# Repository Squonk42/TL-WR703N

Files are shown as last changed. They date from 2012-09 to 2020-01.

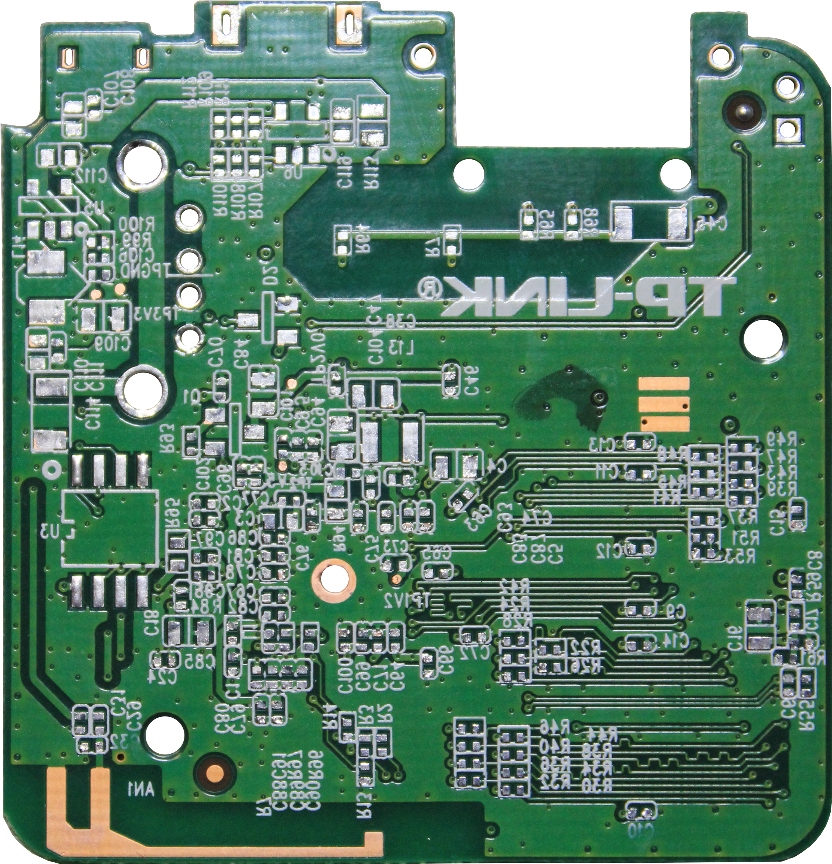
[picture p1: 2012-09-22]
Pictures/TL-WR703N Bare Board Bottom Mirrored.jpg

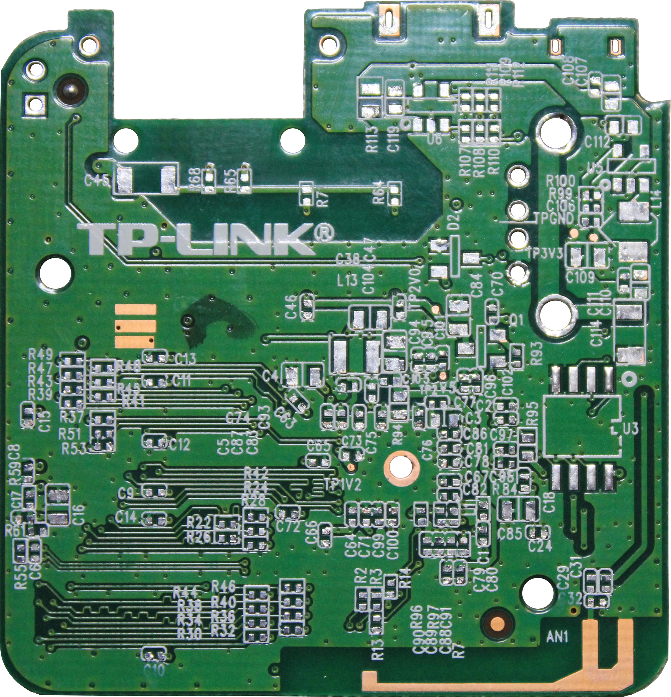
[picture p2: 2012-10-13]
Pictures/TL-WR703N Bare Board Bottom.jpg

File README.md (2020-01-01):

TL-WR703N
=========

Reverse Engineering work on the TP-LINK® TL-WR703N 150M 802.11n Wi-Fi Router

Check the http://squonk42.github.com/TL-WR703N/ web page for details.

### What?
Unlike what it is marketed for, the TP-LINK® TL-WR703N is not a “3G travel router”: it does not include a 3G modem at all, it simply means that the firmware support external USB 3G modems!

Despite this shortcoming, at less than $23, this device is the cheapest Wi-Fi router you can get west of the Pecos River! For this ridiculously low price, you get:

* A clean, small (57 mm x 57 mm x 18 mm) shiny white/light blue cover plastic case with rounded corners that is pretty easy to open with just a spudger or any other thin and resistant tool
* An Atheros AR9331 chipset with
 * An Atheros AR7040 400 MHz MISP24kc CPU
 * Integrated 802.11n 150 Mbps (130 Mbps real) Wi-Fi with 20 dBm (100 mW) output power
* 4 MB of serial (SPI) Flash memory
* 32 MB of DDR SDRAM
* An USB 2.0 host port
* A shielded Ethernet 10/100 Mbps RJ45 jack
* An external power supply using a provided wall plug via a micro-USB socket
* A software-controlled reset pinhole switch
* A blue surface-mounted LED (that can be replaced by a 3 mm through-hole LED)
* A built-in Wi-Fi printed antenna (that can be replaced by an external one)
* An UART accessible via 2 tiny pads that provides access to the uBoot bootloader and the Linux 2.6 console

This device was released in August 2011 in China, and is not exported, though it is easy to get one on eBay.

There is also a closely related sister device as the TP-LINK® TL-MR3020 for the export market, with the following differences:

* It is CE/FCC certified
* It has 4 additional surface-mounted LEDs
* It has an additional sliding switch with 3 positions
* The reset button is combined with the WPS LED
* It has 2 Wi-Fi printed antennas, but only one is actually used
* The RJ45 Ethernet jack is not shielded
* The UART is available on a nice 0.1” pitch through-hole connector (not mounted)
* It is larger: 67 mm x 74 mm x 22 mm)
* It is more expensive: $39 on eBay

### Why?
Because of these interesting characteristics, people started to imagine unforeseen applications for the cheapest available embedded Linux platform on the market, ranging from software-only firmware customization, to hardware hacks involving fine pitch soldering in order to control various physical devices.

The manufacturer (TP-LINK) is making its best efforts to comply with the requirements of the GPL license by providing access to [sources releases of the modified GPL software used in the original firmware](http://www.tp-link.com/en/support/gpl/) (actually, those of the related [TL-MR3020 device](http://www.tp-link.com/en/support/gpl/?categoryid=547), but they are close enough). Although not useable as is, all these modifications has been ported to several existing embedded Linux distributions, and the dedicated embedded [OpenWRT distribution](https://openwrt.org/) is an excellent choice for its easy build system and support for bleeding-edge packages.

Naturally, the hardware-focused projects using the TL-WR703N tend to be centralized in a few OpenWRT forum threads ([[1]](https://forum.openwrt.org/viewtopic.php?id=36471), [[2]](https://forum.openwrt.org/viewtopic.php?id=38994), [[3]](https://forum.openwrt.org/viewtopic.php?id=39567), [[4]](https://forum.openwrt.org/viewtopic.php?id=34437), and [[5]](https://forum.openwrt.org/viewtopic.php?id=31729)), and rapidly focused on the research of available I/O resources and low-level electronic understanding. In this regard, the TL-WR703N router suffers from a complete lack of information reagarding its hardware implementation:

* The datasheet for the main chip (Atheros AR9331) is only available under NDA (Non-Disclosure Agreement)
* No available schematic, layout or BOM (Bill Of Materials) files

Although some progress has been made, like an almost exhaustive main AR9331 chip pinout and a component-by-component description, only a full reverse-engineering work can provide the answers to all the questions people will have on the TL-WR703N hardware.

So the goal of this reverse-engineering of the TP-LINK® TL-WR703N router hardware is not to reproduce the device as is, as both the main chip is not available for retail, and because it would be difficult to beat the already low prices achieved by the Chinese manufacturer anyway. But the main purpose of this work is to provide the knowledge required to fully understand the hardware of this amazing little device.

### Who?
This is the work of a single person (Michel Stempin), based on the [TP-LINK® TL-WR703N teardown](http://www.kean.com.au/oshw/WR703N/teardown/) performed by Kean from the OpenWRT forum.

### Where?
All the resulting files are available in the [corresponding GitHub repository](https://github.com/Squonk42/TL-WR703N), and discussions are taking place into the corresponding threads from the [OpenWRT forum](https://forum.openwrt.org/).

The CAD files are designed using [EagleCAD v6.10](http://www.cadsoftusa.com/eagle-pcb-design-software/?language=en). Despite the fact that the free version is limited to 2 layers only and that the boards has more layers than that, this should not be too much of a problem, as there are only a few signals located into the internal layers.

So any question, idea, remark can be posted there!

### When?
This work took around 150 hours (2 week-ends and all the evenings in-between on my spare time) to produce a first PCB layout from the raw PCB top and bottom pictures.

But spare time costs nothing, and hobbyist motivation is higher than normal paid work!

### How?
If I remember correctly, Kean took the PCB pictures using an 18 Mpx camera. Removing all borders and cleaning up the original pictures, this resulted into images of 3090 x 3210 pixels. As the PCB is approximately 1.9" x 1.9", the achieved resolution is something close to 1600 dpi, or a little bit better than a common 1200/2400 dpi flat bed scanner in one direction, worse in the other.

The drawback is that using a camera with a large depth of field, the image is not perfect. It contains:
* perspective (i.e. board edges are not parallel, and are not parallel either to the picture edges)
* a "barrel" effect due to the lens in macro mode
* pixels are not necessarily "square" in X and Y
* the actual scale is unknown

The first step was thus to clean up the picture using the perspective correction function of PS as a picture editing tool to straighten borders.

As for the other 2 next problems, the trick was to find something into these pictures that can be taken as a reference with known dimensions: the best guess was to take a large chip with numerous evenly-spaced pads, like the main AR9331 SoC U1 or the SDRAM chip U2. Using the same graphical editing program as used above, tools for correcting the lens "barrel" effect and scale differently in X and Y were used to get perfectly square pixels.

Now, both sides couldn't be directly superimposed: holes, vias and the PCB contour itself did not match correctly. A good way to fix this problem was to use PS's "puppet warp transform" tool with the 2 PCB sides on separate layers with transparency. This tool allowed to place and drag pins over the picture, so it could be stretched locally. Using this technique, it was possible to make both sides match perfectly by first placing pins at the 4 corners, then adding more pins as required until a perfect match was obtained.

At this point, 2 perfectly matched/square pictures with a resolution close to the original snapshots were available.

The last problem related to unknown scale required to perform a resize operation on these pictures, so they can be superimposed with the PCB in the ECAD software used ([EagleCAD](http://www.cadsoftusa.com/eagle-pcb-design-software/?language=en)). Again, the same chips as above were taken as references with known dimensions. Based on the datasheets, their footprint was first created into EagleCAD with exact "real" dimensions, then placed into an empty PCB file.

As I still use Windows XP, I had to use the [Glass2K](http://chime.tv/products/glass2k.shtml) utility to get either a transparent EagleCAD or picture window. Putting the EagleCAD window as large as possible on my screen, I aligned the footprint with the picture, by scaling the picture so that the round 25% picture scale was matching the EagleCAD full screen display.

By adjusting EagleCAD zoom factor from the default 1.2 to 2, it is now possible on my screen to scale the picture to 50/100/200% while zooming along with EagleCAD, and thus zoom into details "almost" easily.

That was all for the pictures, no editing any more! The drawback is that because of this last step, they are adjusted to my screen setup and cannot be shared with others easily.

The next big job was then to create all the component footprints as an EagleCAD part library. Having 2 screens helped a lot in this case, and using transparency as above, it was possible to check that the footprint was correct directly into the picture. Still, this was a tedious job. As I was doing that, I took this opportunity to also create the corresponding schematic symbols and the parts for tying the symbols and the footprints together.

Once all the parts were created, I placed them onto the PCB/picture as accurately as possible, then started to route all traces in between. There was a trick to integrate existing vias into a trace: I had to get info on the via to find its signal name, then name the trace using the same name, so they both belong to the same signal. Also, when there was only a single signal pad to connect to a via, I had to artificially add a dummy part to first create a ratsnet between 2 pads, get via info/name the ratsnest as explained, then destroy the dummy part...

I used a 1 mm/0.05 mm grid, and only a few different trace widths. However, I had to create 2 signal "classes" with different clearance values to create the correct ground/power planes.

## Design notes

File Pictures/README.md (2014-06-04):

**Note:** The "TL-WR703N Schematic EagleCAD.png" file is huge (26731x18331), so opening it directly within your browser may cause it to crash!

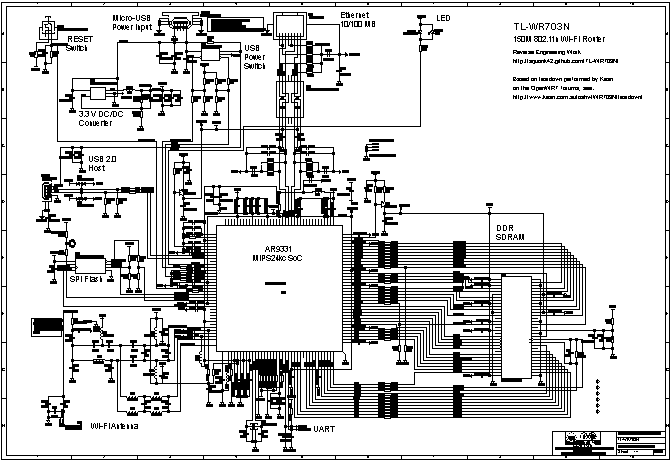
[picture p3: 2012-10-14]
Pictures/TL-WR703N Schematic LoRes.png

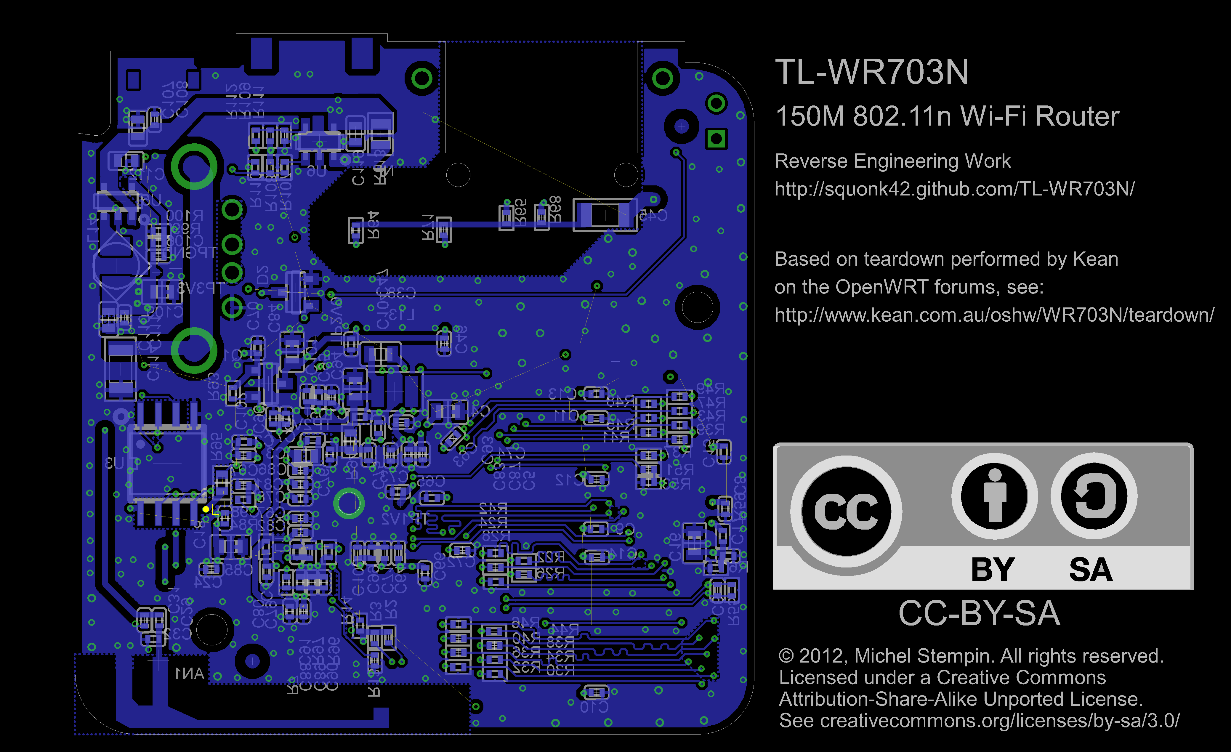
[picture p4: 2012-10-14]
Pictures/TL-WR703N Bottom EagleCAD.png

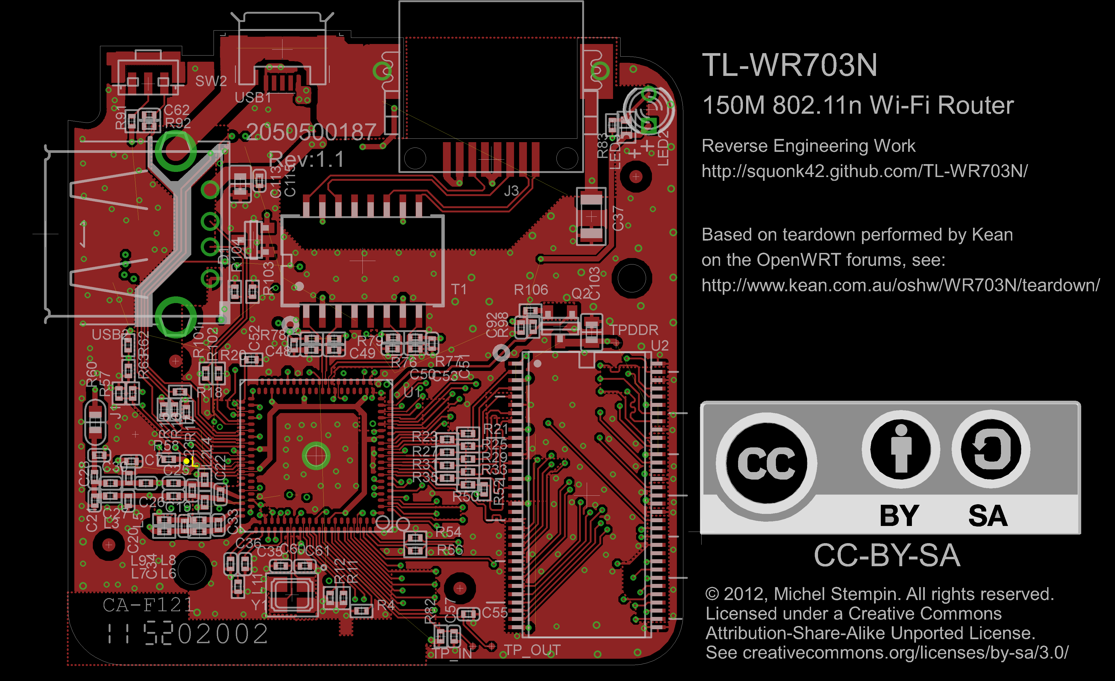
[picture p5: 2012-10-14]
Pictures/TL-WR703N Top EagleCAD.png

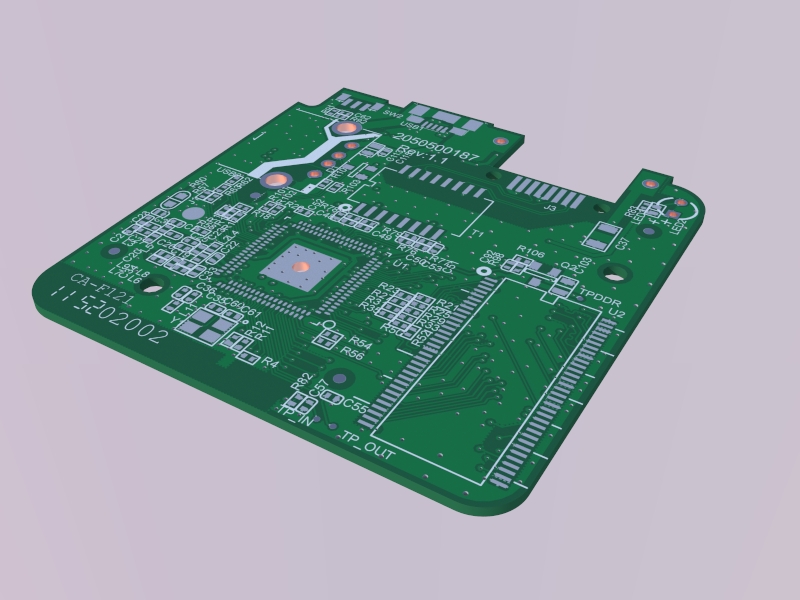
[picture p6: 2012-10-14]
Pictures/TL-WR703N 3D.jpg

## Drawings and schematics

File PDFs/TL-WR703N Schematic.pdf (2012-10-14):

# TL-WR703N

# 150M 802.11n Wi-Fi Router

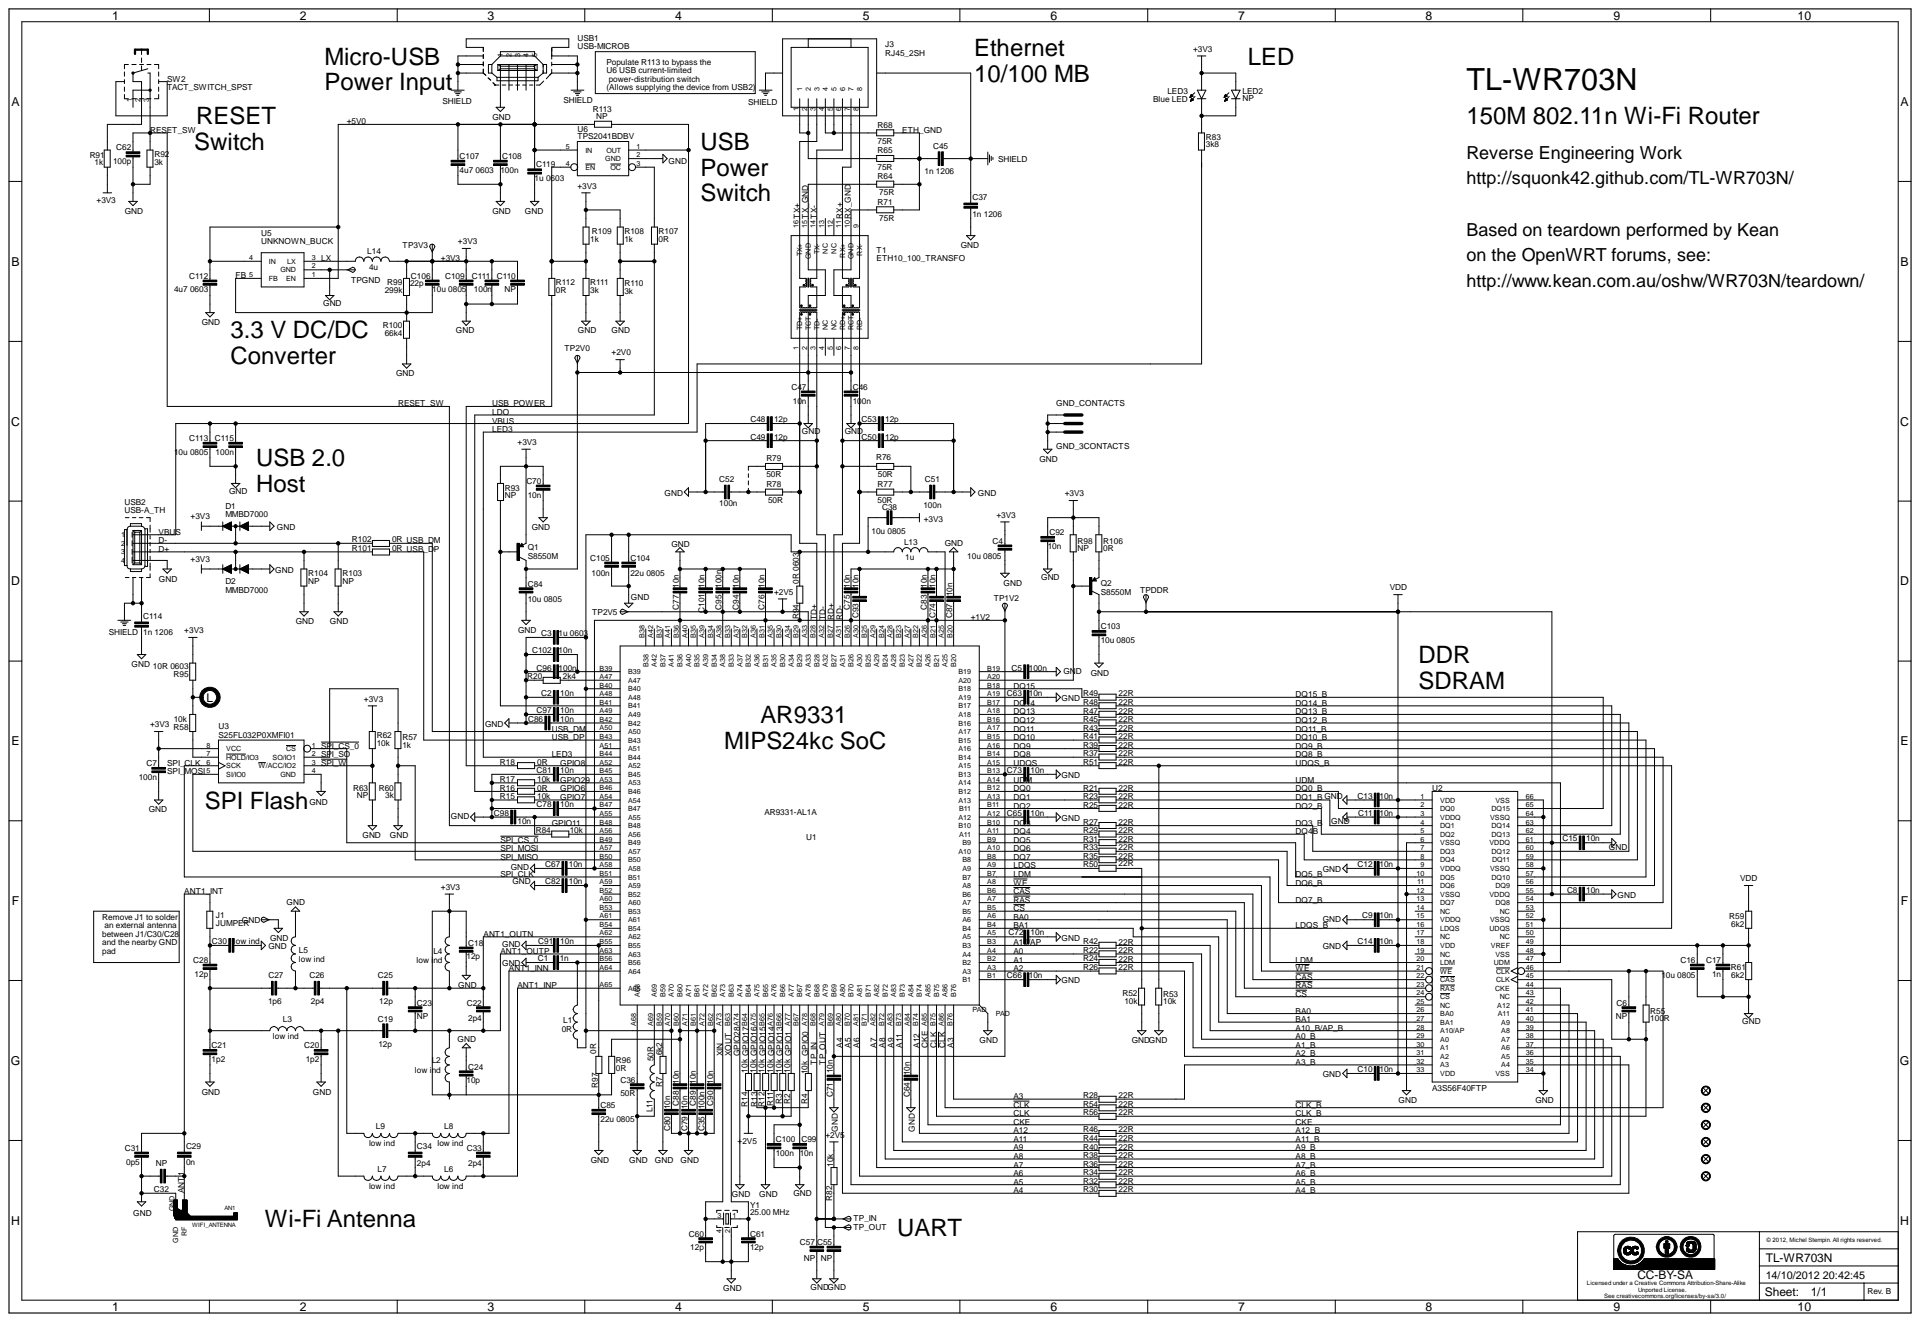
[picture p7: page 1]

Populate R113 to bypass the
U6 USB current-limited
power-distribution switch
(Allows supplying the device from USB2)

Reverse Engineering Work
http://squonk42.github.com/TL-WR703N/

Based on teardown performed by Kean
on the OpenWRT forums, see:
http://www.kean.com.au/oshw/WR703N/teardown/

D+ | R101 0R USB_DP

Remove J1 to solder
an external antenna
between J1/C30/C28
and the nearby GND
pad

Licensed under a Creative Commons Attribution-Share-Alike
See creativecommons.org/licenses/by-sa/3.0/

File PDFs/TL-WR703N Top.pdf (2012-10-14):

2050500187

# TL-WR703N

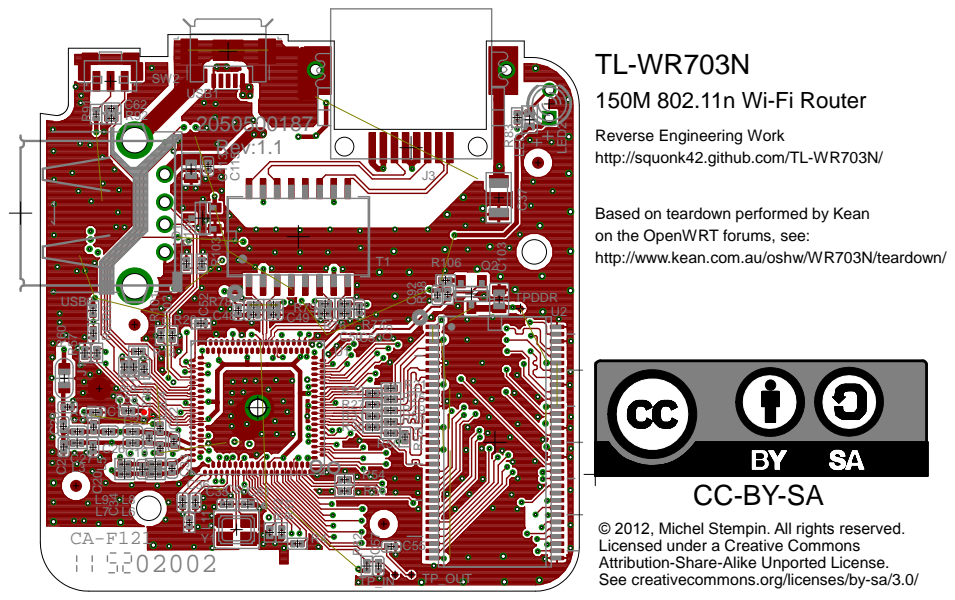
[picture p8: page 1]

LED2
Reverse Engineering Work
http://squonk42.github.com/TL-WR703N/

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

© 2012, Michel Stempin. All rights reserved.
Licensed under a Creative Commons
Attribution-Share-Alike Unported License.
See creativecommons.org/licenses/by-sa/3.0/

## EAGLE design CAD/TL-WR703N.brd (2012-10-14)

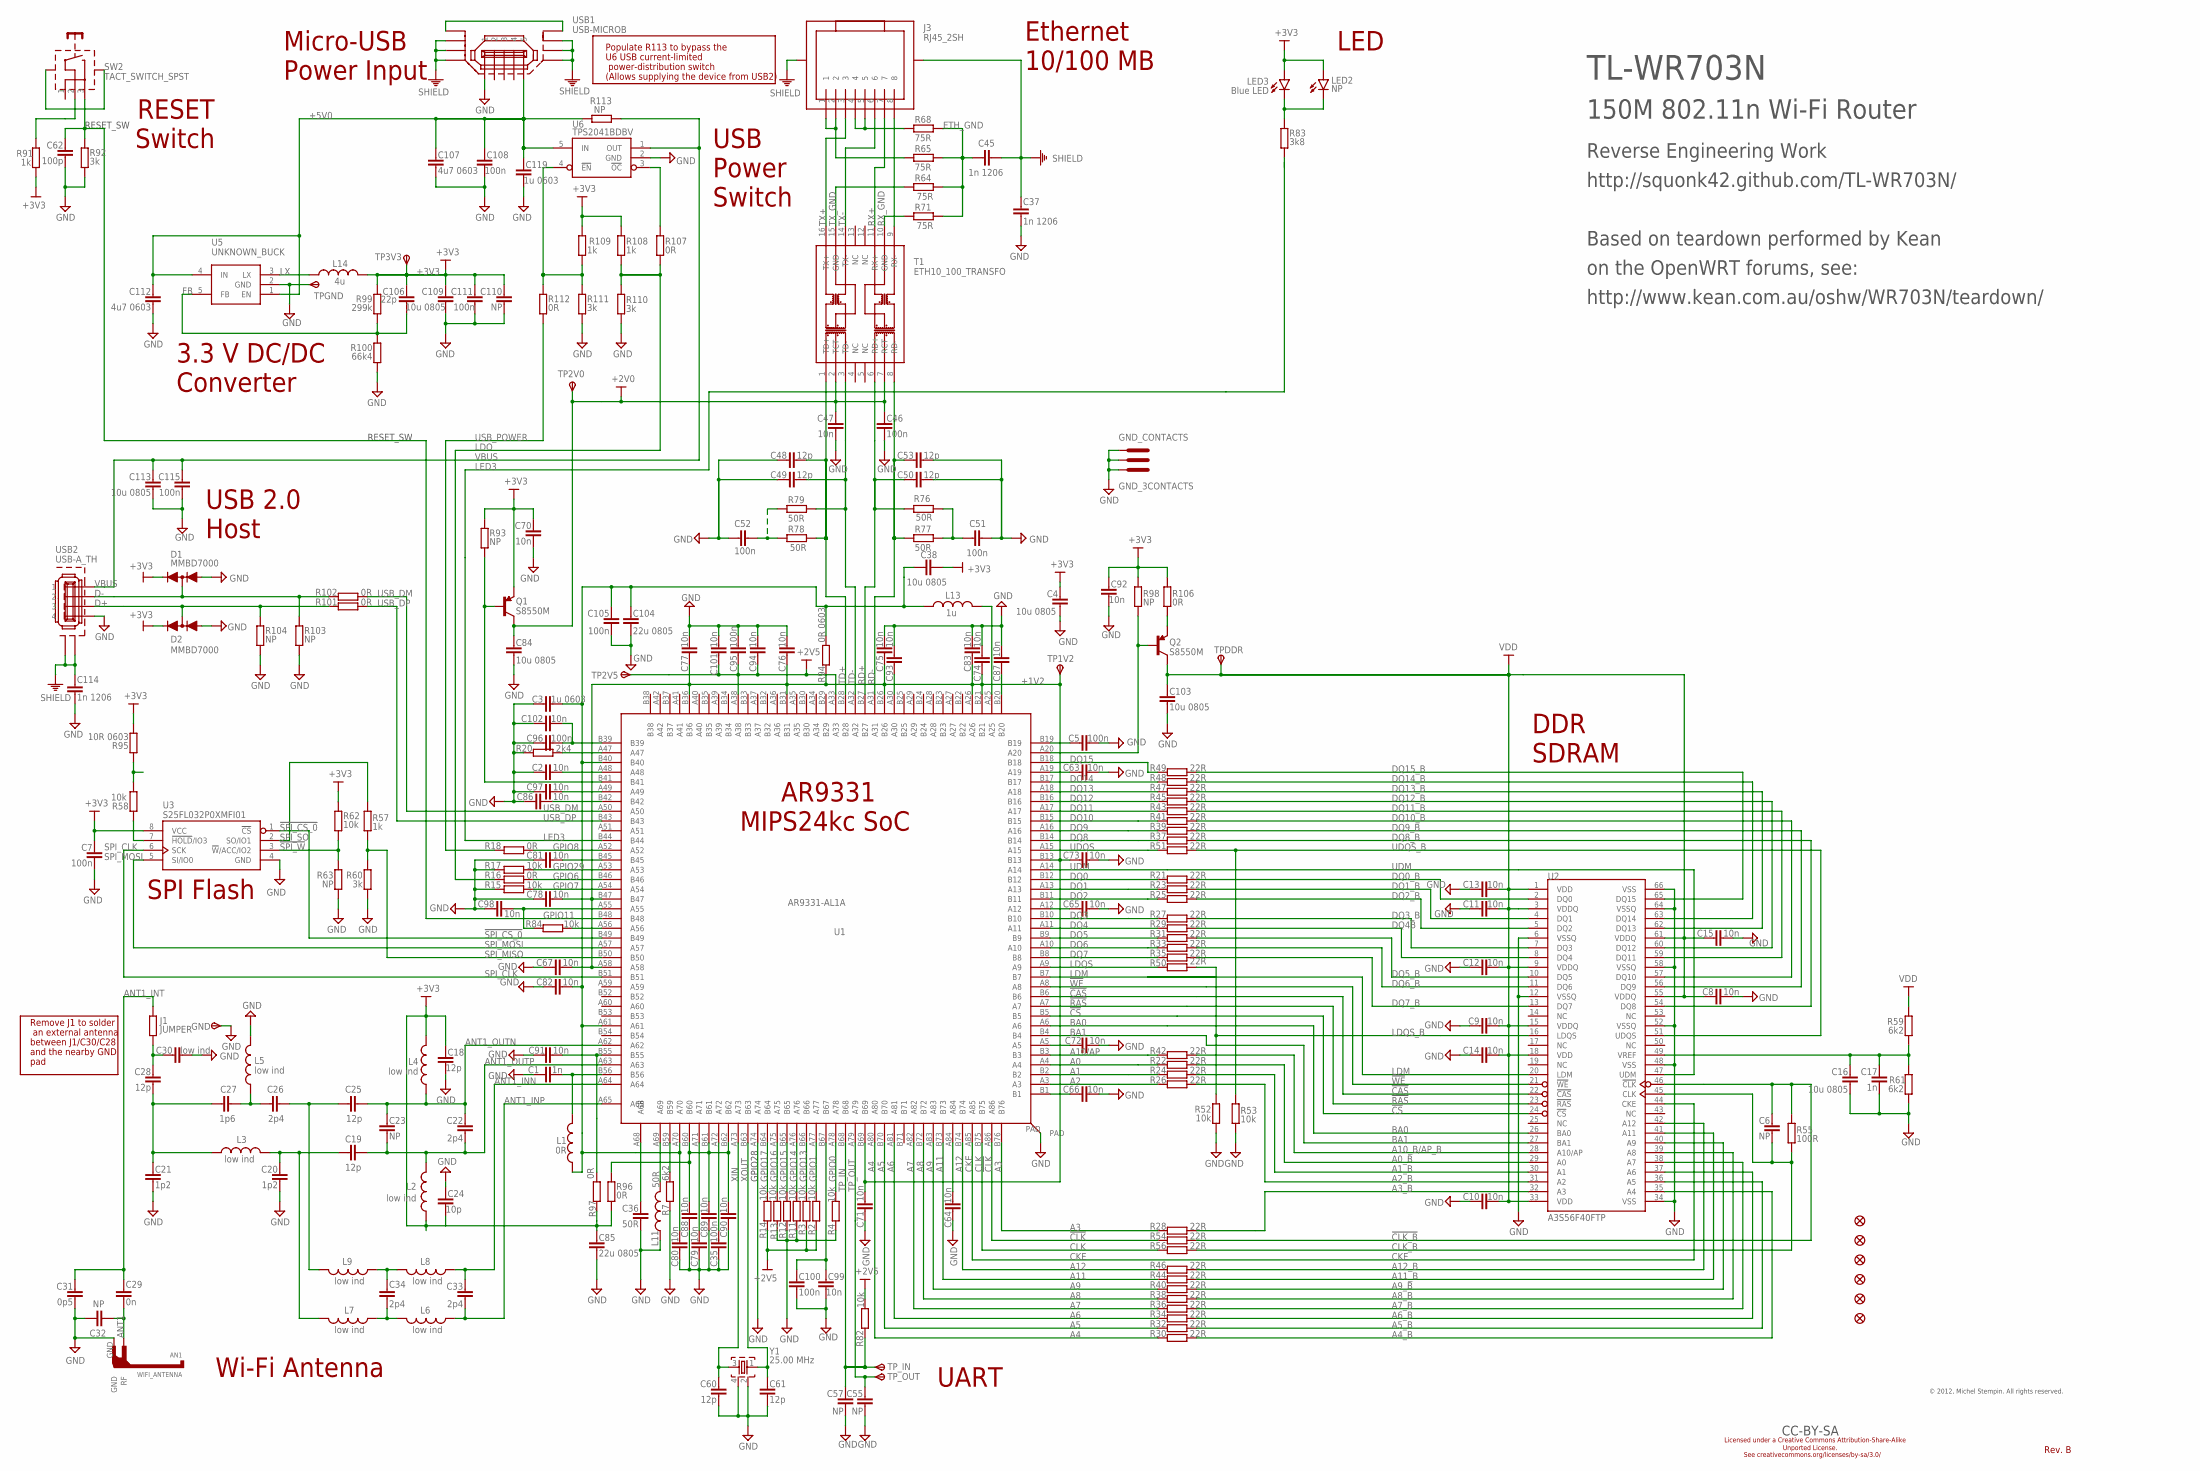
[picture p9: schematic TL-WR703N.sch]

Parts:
AN1: WIFI_ANTENNA
C1, C17: 1n; C0402
C2, C8, C9, C10, C11, C12, C13, C14, C15, C47, C63, C64, C65, C66, C67, C70, C71, C72, C73, C74, C75, C76, C77, C78, C79, C80, C81, C82, C83, C86, C87, C88, C89, C90, C91, C92, C93, C94, C97, C98, C99, C101, C102: 10n; C0402
C3, C119: 1u 0603; C0603
C4, C16, C38, C84, C103, C109, C113: 10u 0805; C0805
C5, C7, C35, C46, C51, C52, C95, C96, C100, C105, C108, C111, C115: 100n; C0402
C6, C23, C32, C55, C57: NP; C0402
C18, C19, C25, C28, C48, C49, C50, C53, C60, C61: 12p; C0402
C20, C21: 1p2; C0402
C22, C26, C33, C34: 2p4; C0402
C24: 10p; C0402
C27: 1p6; C0402
C29: 0n; C0402
C30: low ind; C0402
C31: 0p5; C0402
C36: 50R; C0402
C37, C45, C114: 1n 1206; C1206
C62: 100p; C0402
C85, C104: 22u 0805; C0805
C106: 22p; C0402
C107, C112: 4u7 0603; C0603
C110: NP; C0603
D1, D2: MMBD7000; SOT23-3
E$1, E$2, E$3, E$4, E$5, E$6: FIDUCIAL
E$7: CC-BY-SA
GND: TEST_PAD_SHIELD; SHIELD_PAD
GND_CONTACTS: GND_3CONTACTS; GND_3CONTACT
J1: JUMPER; J0603
J3: RJ45_2SH; RJ45_LP_RA_SMT
L1: 0R; L0402
L2, L3, L4, L5, L6, L7, L8, L9: low ind; L0402
L11: 50R; L0402
L13: 1u; L1008
L14: 4u; FERRITE_SELF
LED2: NP; LED3MM
LED3: Blue LED; LED0603
Q1, Q2: S8550M; SOT23-3
R2, R3, R4, R11, R12, R13, R14, R15, R17, R52, R53, R58, R62, R82, R84: 10k; R0402
R7, R59, R61: 6k2; R0402
R16, R18, R96, R97, R101, R102, R106, R107, R112: 0R; R0402
R20: 2k4; R0402
R21, R22, R23, R24, R25, R26, R27, R28, R29, R30, R31, R32, R33, R34, R35, R36, R37, R38, R39, R40, R41, R42, R43, R44, R45, R46, R47, R48, R49, R50, R51, R54, R56: 22R; R0402
R55: 100R; R0402
R57, R91, R108, R109: 1k; R0402
R60, R92, R110, R111: 3k; R0402
R63, R93, R98, R103, R104: NP; R0402
R64, R65, R68, R71: 75R; R0402
R76, R77, R78, R79: 50R; R0402
R83: 3k8; R0402
R94: 0R 0603; R0603
R95: 10R 0603; R0603
R99: 299k; R0402
R100: 66k4; R0402
R113: NP; R0805
SW2: TACT_SWITCH_SPST; TACT_SWITCH_SPST_RA_SMT
T1: ETH10_100_TRANSFO; H1601CG
TP1V2, TP2V0, TP2V5, TP3V3: TEST_PAD
TPDDR: TEST_PAD
TPGND: TEST_PAD
TP_IN: TEST_PAD
TP_OUT: TEST_PAD
U1: AR9331-AL1A; DRMLF164
U2: A3S56F40FTP; TSOP66
U3: S25FL032P0XMFI01; SOP8
U5: UNKNOWN_BUCK; SOT23-5
U6: TPS2041BDBV; SOT23-5
USB1: USB-MICROB
USB2: USB-A_TH
Y1: 25.00 MHz; CRYSTAL_32_25

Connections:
!CAS: U1.B6, U2.22 (!CAS)
!CLK: R54.1, U1.A86
!CLK_B: C6.2, R54.2, R55.2, U2.46 (!CLK)
!CS: U1.B5, U2.24 (!CS)
!RAS: U1.A7, U2.23 (!RAS)
!SPI_CS_0: U1.B49, U3.1 (!CS)
!SPI_W: R62.2, R63.1, U3.3 (!W!/ACC/IO2)
!WE: U1.A8, U2.21 (!WE)
$28: C52.2, R78.1, R79.2
+1V2: C67.2, C71.2, C73.1, C74.2, C75.1, C76.1, C77.2, C78.2, C83.1, R94.2, TP1V2.1, U1.A26, U1.A58, U1.B13, U1.B21, U1.B26, U1.B31, U1.B36, U1.B47, U1.B69
+2V0: C46.1, C47.1, C84.2, Q1.3 (C), T1.2 (TCT), T1.7 (RCT), TP2V0.1
+2V5: C94.2, C95.2, C101.2, R2.1, R3.1, R14.2, R82.1, TP2V5.1, U1.A33, U1.A38
+3V3: C4.2, C7.1, C18.1, C24.1, C38.2, C70.2, C85.2, C92.2, C106.2, C109.2, C110.1, C111.1, D1.2 (C), D2.2 (C), L2.1, L4.2, L14.1, LED2.A, LED3.A, Q1.2 (E), R62.1, R91.1, R93.2, R95.1, R96.2, R97.2, R98.2, R99.2, R106.2, R108.2, R109.1, TP3V3.1, U3.8 (VCC)
+5V0: C107.2, C108.2, C112.1, C119.1, R113.1, U5.1 (EN), U5.4 (IN), U6.5 (IN), USB1.VBUS (5)
A0: R22.1, U1.A4
A0_B: R22.2, U2.29 (A0)
A1: R24.1, U1.B2
A1_B: R24.2, U2.30 (A1)
A2: R26.1, U1.A3
A2_B: R26.2, U2.31 (A2)
A3: R28.1, U1.B76
A3_B: R28.2, U2.32 (A3)
A4: R30.1, U1.A80
A4_B: R30.2, U2.35 (A4)
A5: R32.1, U1.B70
A5_B: R32.2, U2.36 (A5)
A6: R34.1, U1.A81
A6_B: R34.2, U2.37 (A6)
A7: R36.1, U1.A82
A7_B: R36.2, U2.38 (A7)
A8: R38.1, U1.B72
A8_B: R38.2, U2.39 (A8)
A9: R40.1, U1.A83
A9_B: R40.2, U2.40 (A9)
A10/AP: R42.1, U1.B3
A10_B/AP_B: R42.2, U2.28 (A10/AP)
A11: R44.1, U1.B73
A11_B: R44.2, U2.41 (A11)
A12: R46.1, U1.B74
A12_B: R46.2, U2.42 (A12)
ANT1: AN1.RF, C29.2, C32.2
ANT1_INN: C33.2, L8.1, U1.A64
ANT1_INP: C33.1, L6.1, U1.A65
ANT1_INT: C29.1, C31.1, J1.2
ANT1_OUTN: C22.2, C23.2, C25.2, L4.1, U1.A62
ANT1_OUTP: C19.2, C22.1, C23.1, L2.2, U1.A63
BA0: U1.A6, U2.26 (BA0)
BA1: U1.B4, U2.27 (BA1)
CKE: U1.A85, U2.44 (CKE)
CLK: R56.1, U1.B75
CLK_B: C6.1, R55.1, R56.2, U2.45 (CLK)
D+: D2.3 (M), R101.1, R104.1, USB2.3
D-: D1.3 (M), R102.1, R103.1, USB2.2
DQ0: R21.2, U1.B12
DQ0_B: R21.1, U2.2 (DQ0)
DQ1: R23.2, U1.A13
DQ1_B: R23.1, U2.4 (DQ1)
DQ2: R25.2, U1.B11
DQ2_B: R25.1, U2.5 (DQ2)
DQ3: R27.2, U1.B10
DQ3_B: R27.1, U2.7 (DQ3)
DQ4: R29.2, U1.A11
DQ4B: R29.1, U2.8 (DQ4)
DQ5: R31.2, U1.B9
DQ5_B: R31.1, U2.10 (DQ5)
DQ6: R33.2, U1.A10
DQ6_B: R33.1, U2.11 (DQ6)
DQ7: R35.2, U1.B8
DQ7_B: R35.1, U2.13 (DQ7)
DQ8: R37.1, U1.B14
DQ8_B: R37.2, U2.54 (DQ8)
DQ9: R39.1, U1.A16
DQ9_B: R39.2, U2.56 (DQ9)
DQ10: R41.1, U1.B15
DQ10_B: R41.2, U2.57 (DQ10)
DQ11: R43.1, U1.A17
DQ11_B: R43.2, U2.59 (DQ11)
DQ12: R45.1, U1.B16
DQ12_B: R45.2, U2.60 (DQ12)
DQ13: R47.1, U1.A18
DQ13_B: R47.2, U2.62 (DQ13)
DQ14: R48.1, U1.B17
DQ14_B: R48.2, U2.63 (DQ14)
DQ15: R49.1, U1.B18
DQ15_B: R49.2, U2.65 (DQ15)
ETH_GND: C45.2, R64.1, R65.2, R68.2, R71.1
FB: C106.1, R99.1, R100.2, U5.5 (FB)
GND: AN1.GND, C1.2, C2.2, C3.2, C4.1, C5.2, C7.2, C8.2, C9.1, C10.1, C11.1, C12.1, C13.1, C14.1, C15.2, C16.1, C17.1, C18.2, C20.1, C21.1, C24.2, C30.2, C31.2, C32.1, C35.1, C36.1, C37.1, C46.2, C47.2, C48.1, C49.2, C50.1, C51.1, C52.1, C53.2, C55.2, C57.1, C60.1, C61.2, C62.1, C63.1, C64.1, C65.2, C66.1, C67.1, C70.1, C71.1, C72.1, C73.2, C74.1, C75.2, C76.2, C77.1, C78.1, C79.2, C80.2, C81.1, C82.1, C83.2, C84.1, C85.1, C86.1, C87.2, C88.2, C89.2, C90.2, C91.1, C92.1, C93.1, C94.1, C95.1, C96.1, C97.2, C98.2, C99.1, C100.1, C101.1, C102.1, C103.2, C104.2, C105.2, C107.1, C108.1, C109.1, C110.2, C111.2, C112.2, C113.1, C114.2, C115.1, C119.2, D1.1 (A), D2.1 (A), GND.1, GND_CONTACTS.GND$1, GND_CONTACTS.GND$2, GND_CONTACTS.GND$3, L5.2, L11.1, R4.2, R7.2, R11.1, R12.1, R13.2, R15.1, R17.1, R20.2, R52.2, R53.1, R60.1, R61.2, R63.2, R92.1, R100.1, R103.2, R104.2, R110.2, R111.1, TPGND.1, U1.A74, U1.PAD, U2.6 (VSSQ), U2.12 (VSSQ), U2.34 (VSS), U2.48 (VSS), U2.52 (VSSQ), U2.58 (VSSQ), U2.64 (VSSQ), U2.66 (VSS), U3.4 (GND), U5.2 (GND), U6.2 (GND), USB1.GND (1), USB2.4, Y1.2, Y1.4
GPIO0: R4.1, U1.A78
GPIO1: R2.2, U1.A77
GPIO6: R16.2, U1.B46
GPIO7: R15.2, U1.A54
GPIO8: R18.2, U1.A52
GPIO11: C62.2, R92.2, SW2.3, U1.B48
GPIO13: R3.2, U1.B66
GPIO14: R11.2, U1.A76
GPIO15: R12.2, U1.B65
GPIO16: R13.1, U1.A75
GPIO17: R14.1, U1.B64
GPIO29: R17.2, U1.A53
LDM: U1.B7, U2.20 (LDM)
LDO: R16.1, R107.1, R108.1, R110.1
LDQS: R50.2, U1.A9
LDQS_B: R50.1, R52.1, U2.16 (LDQS)
LED3: R83.1, U1.B44
LX: L14.2, U5.3 (LX)
unnamed: C79.1, U1.A71
RD+: C50.2, R76.2, T1.6 (RD+), U1.B27
RD-: C53.1, R77.1, T1.8 (RD-), U1.A31
RX+: J3.7, T1.11 (RX+)
RX-: J3.8, T1.9 (RX-)
RX_GND: R71.2, T1.10 (GND)
S$15: C99.2, C100.2, U1.B67
S$17: C19.1, C20.2, L3.2, L7.2
S$18: C3.1, C38.1, C80.1, C82.2, C104.1, C105.1, L1.2, L13.1, R94.1, U1.A61, U1.A70, U1.B40
S$36: C65.1, U1.A12
S$44: C16.2, C17.2, R59.2, R61.1, U2.49 (VREF)
S$54: C51.2, R76.1, R77.2
S$55: LED2.K (C), LED3.C, R83.2
S$73: C34.1, L6.2, L7.1
S$76: C1.1, L1.1, U1.B56
S$78: R58.1, R95.2
S$80: C21.2, C27.1, C28.1, L3.1
S$87: C28.2, C30.1, J1.1
S$94: C26.1, C27.2, L5.1
S$95: R20.1, U1.A47
S$102: C86.2, U1.B42
S$103: C5.1, C87.1, U1.B19, U1.B20
S$106: R91.2, SW2.2
S$107: SW2.S$1 (SH$1), SW2.S$2 (SH$2)
S$110: USB1.P$1 (M0), USB1.P$2 (M7)
S$114: C35.2, U1.A72
S$115: L11.2, U1.A69
S$116: R7.1, U1.B59
S$117: C88.1, C89.1, C90.1, R96.1, U1.B60, U1.B61, U1.B62
S$121: C63.2, U1.A19
S$122: C81.2, U1.B45
S$125: C91.2, R97.1, U1.B55
S$127: C34.2, L8.2, L9.1
S$128: R109.2, R111.2, R112.2, U6.4 (!EN)
S$130: C25.1, C26.2, L9.2
S$133: C96.2, C102.2, U1.B39
S$135: C97.1, U1.A49
S$136: C98.1, R84.1, U1.A55
S$137: R58.2, U3.7 (!HOLD!/IO3)
S$138: R84.2, U1.A56
S$145: L13.2, U1.A25
S$152: C2.1, U1.A48
S$192: C64.2, C66.2, U1.A84, U1.B1
S$194: R107.2, U6.3 (!OC)
S$203: Q1.1 (B), R93.1, U1.B41
S$290: J3.1, J3.2, R65.1
S$291: J3.4, J3.5, R68.1
S$354: C36.2, U1.A68
S$380: Q2.2 (E), R106.1
S$409: C93.2, U1.A30
S$430: Q2.1 (B), R98.1, U1.A20
S$434: C72.2, U1.A5
SHIELD: C37.2, C45.1, C114.1, J3.S$1 (SHIELD), J3.S$2 (SHIELD), USB1.S$1 (M1), USB1.S$2 (M2), USB1.S$3 (M3), USB1.S$4 (M4), USB1.S$5 (M5), USB1.S$6 (M6), USB2.S$1 (M1), USB2.S$2 (M2)
SPI_CLK: U1.B51, U3.6 (SCK)
SPI_MISO: R57.2, R60.2, U1.B50
SPI_MOSI: U1.A57, U3.5 (SI/IO0)
SPI_SO: R57.1, U3.2 (SO/IO1)
TD+: C48.2, R78.2, T1.1 (TD+), U1.B28
TD-: C49.1, R79.1, T1.3 (TD-), U1.A32
TP_IN: C57.2, R82.2, TP_IN.1, U1.B68
TP_OUT: C55.1, TP_OUT.1, U1.A79
TX+: J3.3, T1.16 (TX+)
TX-: J3.6, T1.14 (TX-)
TX_GND: R64.2, T1.15 (GND)
UDM: U1.A14, U2.47 (UDM)
UDQS: R51.1, U1.A15
UDQS_B: R51.2, R53.2, U2.51 (UDQS)
USB_DM: R102.2, U1.A50
USB_DP: R101.2, U1.B43
USB_POWER: R18.1, R112.1
VBUS: C113.2, C115.2, R113.2, U6.1 (OUT), USB2.1
VDD: C8.1, C9.2, C10.2, C11.2, C12.2, C13.2, C14.2, C15.1, C103.1, Q2.3 (C), R59.1, TPDDR.1, U2.1 (VDD), U2.3 (VDDQ), U2.9 (VDDQ), U2.15 (VDDQ), U2.18 (VDD), U2.33 (VDD), U2.55 (VDDQ), U2.61 (VDDQ)
XIN: C60.2, U1.A73, Y1.3
XOUT: C61.1, U1.B63, Y1.1

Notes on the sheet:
TL-WR703N
150M 802.11n Wi-Fi Router
Reverse Engineering Work
Based on teardown performed by Kean
on the OpenWRT forums, see:
http://www.kean.com.au/oshw/WR703N/teardown/
http://squonk42.github.com/TL-WR703N/
© 2012, Michel Stempin. All rights reserved.
CC-BY-SA
GPIO28
RESET_SW
Licensed under a Creative Commons Attribution-Share-Alike
See creativecommons.org/licenses/by-sa/3.0/
Unported License.
Rev. B
U6 USB current-limited
power-distribution switch
Populate R113 to bypass the
(Allows supplying the device from USB2)
Remove J1 to solder
an external antenna
between J1/C30/C28
and the nearby GND
pad
SPI Flash
Wi-Fi Antenna
USB 2.0
RESET
Power Input
Ethernet
LED
3.3 V DC/DC
USB
Power
Switch
AR9331
MIPS24kc SoC
Switch
SDRAM
DDR

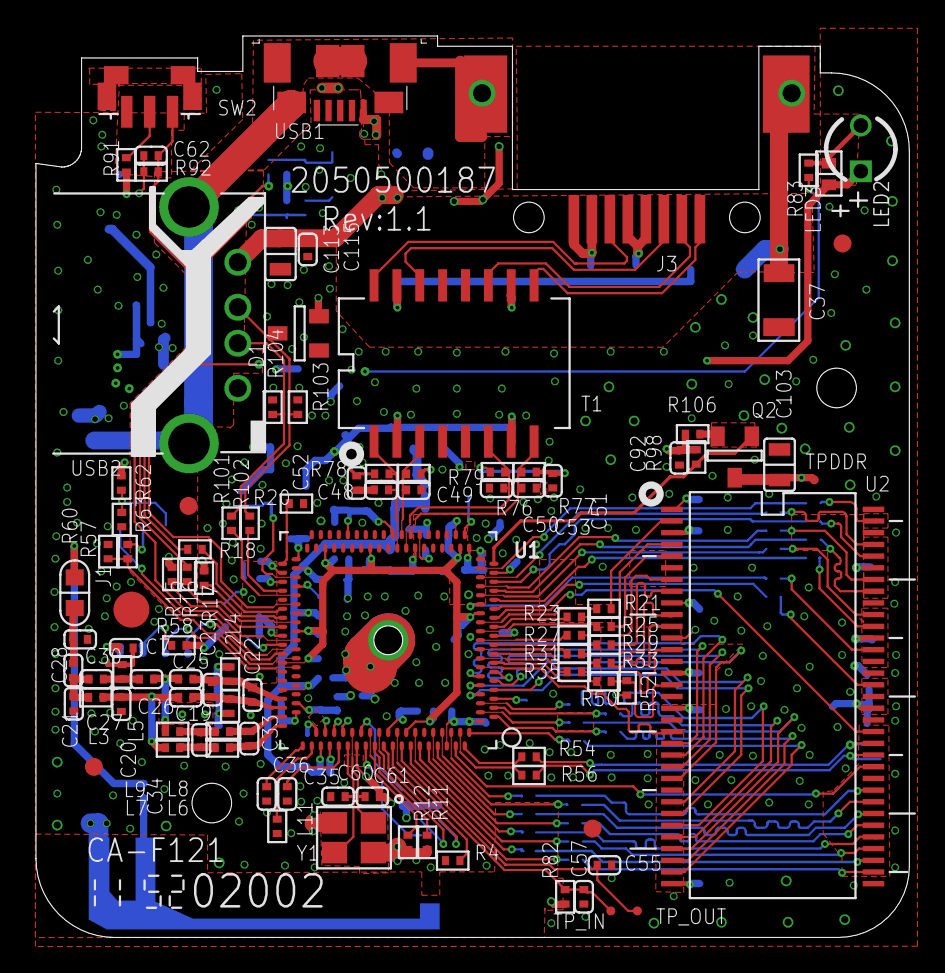
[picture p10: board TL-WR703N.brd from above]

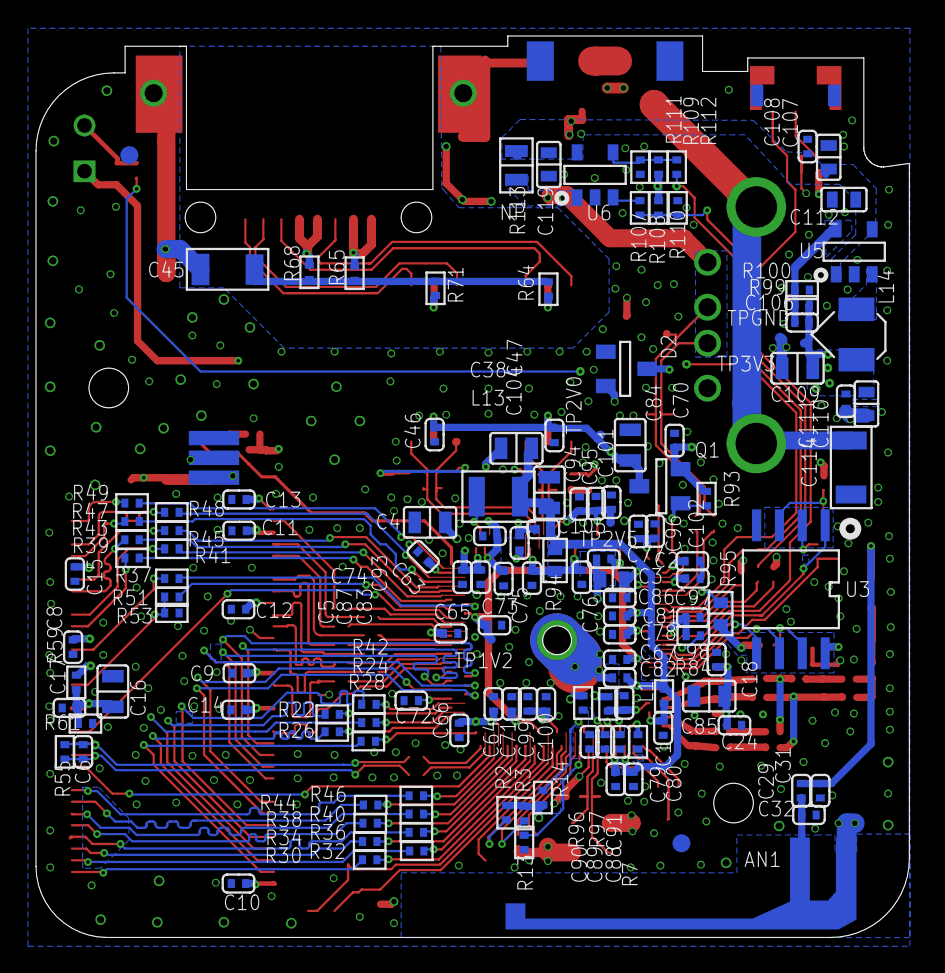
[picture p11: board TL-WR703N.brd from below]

Board: 2 copper layers, 48.5 x 50.1 mm, 241 parts (140 on the bottom side), 180 nets.

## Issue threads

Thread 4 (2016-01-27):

trying to compile wireless driver for RT5350 in openWRT

swamivi, 2016-01-27:
hi guyz,
I know this thread is 2 years old.
but I have a problem.
you mentioned in your comment about difficulties designing own board.
I have solved most of them but facing a big one.
How to calibrate the RT5350 wireless on OpenWRT
I have a board with sample binary on flash.
of which factory partition need to configure using WiFi calibration tool.
I have taken permission to use callibration tool.
Now stuck on driver need to support that tool.
I got the info that they use diffetant private ioctl with help of iwpriv command.
I have also reffered your mt7620 wireless driver code.
it is good work but it does not help me in my problem.
So now I need help regarding how to modify your 7620 driver to support RT5350
I dont expect spoon feeding help but just the point me at the rght dirrection.
I am thinking of creating a branch to your code.
Thanks in advance

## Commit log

2012-09-16 Added initial files
    Board, library, datasheets and pictures
    [TL-WR703N.brd]
2012-09-16 Routed SDRAM
    [TL-WR703N.brd]
2012-09-16 Corrected to traces to SDRAM
    [TL-WR703N.brd]
2012-09-18 Almost completed traces on top side
    [TL-WR703N.brd]
2012-09-19 Definitely good progress on top side!
    [TL-WR703N.brd]
2012-09-22 Looks like the top side is done!
    [TL-WR703N.brd]
2012-09-30 Completed layout reverse engineering!
    [TL-WR703N.brd]
2012-09-30 Corrected a pin mapping in T1
2012-10-04 Connected a few missing pads to GND
    [TL-WR703N.brd]
2012-10-05 Modiied Ethernet Transfo & USB connector symbols
    [TL-WR703N.brd]
2012-10-06 Saved board before linking to schematic
    [TL-WR703N.brd]
2012-10-12 Added schematic & update all other files
    [TL-WR703N.brd, TL-WR703N.sch]
2012-10-12 Minor cleanup
    [TL-WR703N.brd]
2012-10-14 Updated board to Rev. B
    Added missing wire between c21 and C28, and between U1-A33 and +2V5.
    Removed internal via labels after probing with a DMM
    [TL-WR703N.brd, TL-WR703N.sch]

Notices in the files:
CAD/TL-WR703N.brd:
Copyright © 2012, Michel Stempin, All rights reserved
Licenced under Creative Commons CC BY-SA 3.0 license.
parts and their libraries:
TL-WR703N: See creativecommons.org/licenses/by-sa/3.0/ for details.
